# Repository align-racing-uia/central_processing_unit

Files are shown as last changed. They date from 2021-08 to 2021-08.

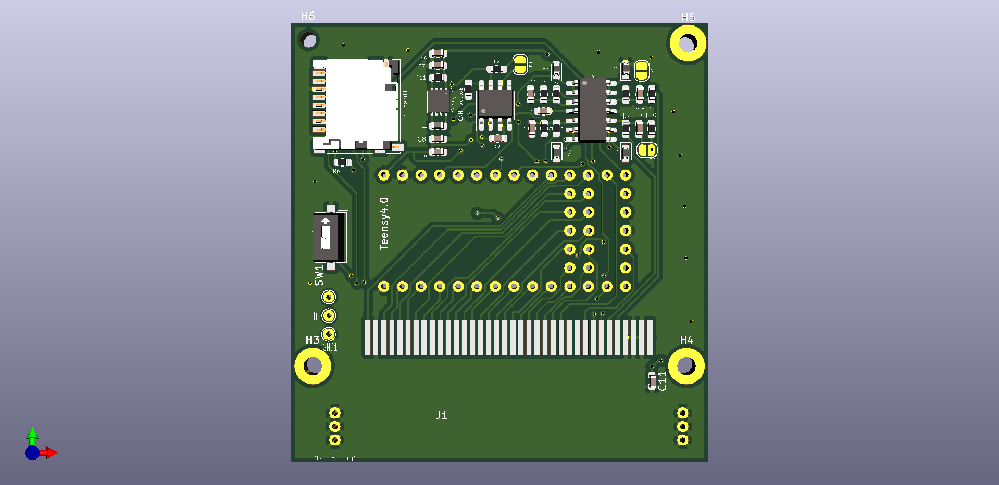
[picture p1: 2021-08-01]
cpu_pcb/breakout/teensy4_header_breakout.png

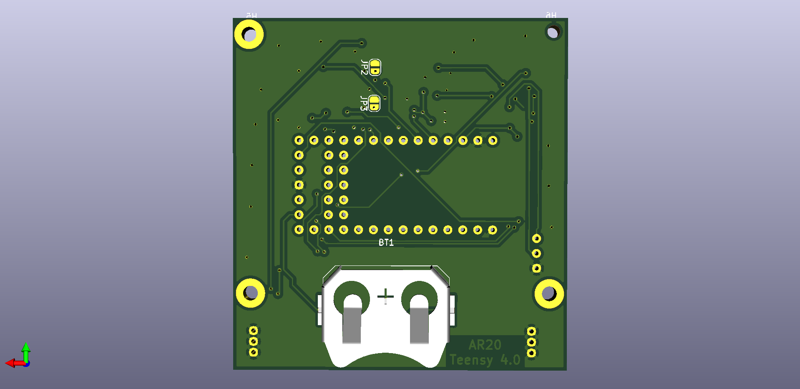
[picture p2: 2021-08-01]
cpu_pcb/breakout/teensy4_header_breakout_back.png

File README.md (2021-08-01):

<h1 align="center"> Central Processing Unit </h1> <br>
<p align="center">
    <a href="http://www.alignracing.no/">
      Align Racing UiA
    </a>
</p>

<!-- START doctoc generate TOC please keep comment here to allow auto update -->
<!-- DON'T EDIT THIS SECTION, INSTEAD RE-RUN doctoc TO UPDATE -->
## Table of contents

- [Introduction](#introduction)
- [Align Racing UiA](#alignracinguia)
- [Rules for file structure](#rulesforfilestructure)
- [License](#license)

<!-- END doctoc generated TOC please keep comment here to allow auto update -->

## Introduction

This is the repository for Align Racing's formula student race car's different systems.

## Align Racing UiA

<a href="http://www.alignracing.no/">Align Racing UiA (AR)</a> is a multidisciplinary student organisation at <a href="https://www.uia.no/">The University of Agder (UiA)</a>, that take part in the world’s largest yearly engineering competition; <a href="https://www.imeche.org/events/formula-student">Formula Student (FS)</a>. The organisation continuously consists of around 60 students, from a wide variety of disciplines. The competition includes developing, building, budgeting and marketing a small scale formula type racing car. AR takes this a bit further by having more focus on developing a strong organisation, open for all disciplines, that gives the members a taste of future work-life.

## Rules

## Contribution

## License
All content included in this Git repository is under the license:

Creative Commons Attribution-NonCommercial-ShareAlike 4.0 International

You are free to:
* <b> Share </b> — copy and redistribute the material in any medium or format
* <b> Adapt </b> — remix, transform, and build upon the material

Under the following terms:
* <b> Attribution </b> — You must give appropriate credit, provide a link to the license, and indicate if changes were made. You may do so in any reasonable manner, but not in any way that suggests the licensor endorses you or your use.
* <b> NonCommercial </b> — You may not use the material for commercial purposes.
* <b> ShareAlike </b> — If you remix, transform, or build upon the material, you must distribute your contributions under the same license as the original.
* <b> No additional restrictions </b> — You may not apply legal terms or technological measures that legally restrict others from doing anything the license permits.

<p align="center">
License
</p>

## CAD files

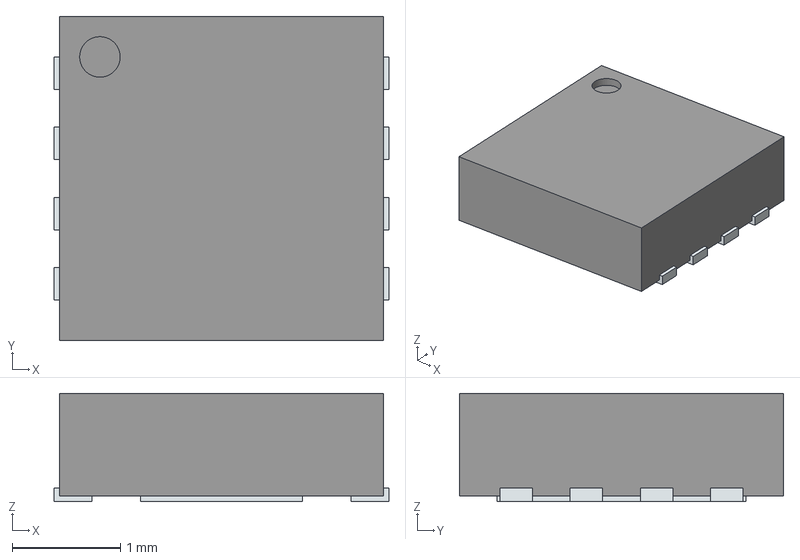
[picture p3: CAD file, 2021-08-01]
cpu_pcb/breakout/NCV890430/NCV890430MW50TXG.stp
3.10 x 3.00 x 1.00 mm
ThermalPin
PinsArrayLR

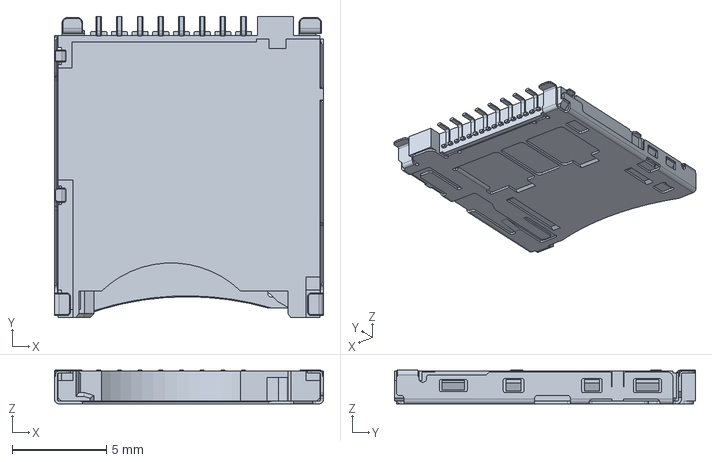
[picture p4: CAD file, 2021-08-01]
cpu_pcb/breakout_2_layers_V2.0/3D_Components/5027740891.stp
14.3 x 16.0 x 1.80 mm

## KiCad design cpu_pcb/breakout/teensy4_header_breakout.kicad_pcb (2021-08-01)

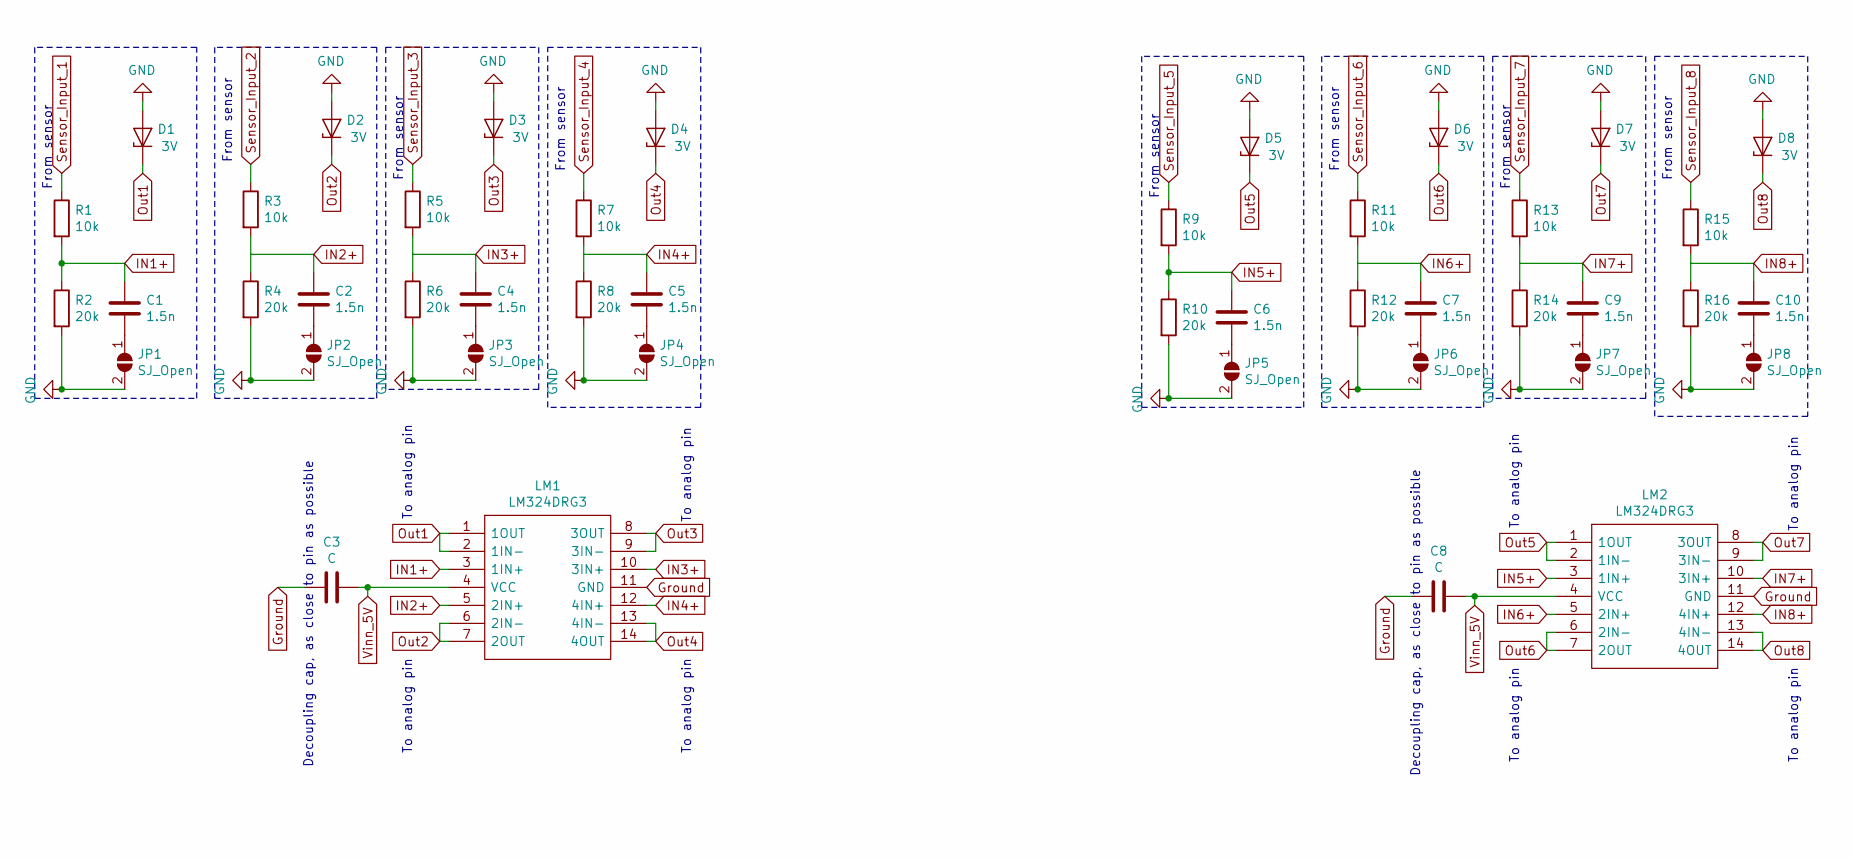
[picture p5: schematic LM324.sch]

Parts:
C1, C2, C4, C5, C6, C7, C9, C10: 1.5n; C_0603_1608Metric
C3, C8: C; C_0603_1608Metric
D1, D2, D3, D4, D5, D6, D7, D8: 3V; D_0603_1608Metric
JP1, JP2, JP3, JP4, JP5, JP6, JP7, JP8: SJ_Open; SolderJumper-2_P1.3mm_Open_RoundedPad1.0x1.5mm
LM1, LM2: LM324DRG3; SOIC-14_3.9x8.7mm_P1.27mm; Manufacturer_Part_Number LM324DRG3; Mouser Part Number 595-LM324DRG3
R1, R3, R5, R7, R9, R11, R13, R15: 10k; R_0603_1608Metric
R2, R4, R6, R8, R10, R12, R14, R16: 20k; R_0603_1608Metric

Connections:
Ground: C3.1, C8.1, D1.2 (A), D2.2 (A), D3.2 (A), D4.2 (A), D5.2 (A), D6.2 (A), D7.2 (A), D8.2 (A), JP1.2 (B), JP2.2 (B), JP3.2 (B), JP4.2 (B), JP5.2 (B), JP6.2 (B), JP7.2 (B), JP8.2 (B), LM1.11 (GND), LM2.11 (GND), R2.2, R4.2, R6.2, R8.2, R10.2, R12.2, R14.2, R16.2; also elsewhere on the board
IN1+: C1.1, LM1.3 (1IN+), R1.2, R2.1
IN2+: C2.1, LM1.5 (2IN+), R3.2, R4.1
IN3+: C4.1, LM1.10 (3IN+), R5.2, R6.1
IN4+: C5.1, LM1.12 (4IN+), R7.2, R8.1
IN5+: C6.1, LM2.3 (1IN+), R9.2, R10.1
IN6+: C7.1, LM2.5 (2IN+), R11.2, R12.1
IN7+: C9.1, LM2.10 (3IN+), R13.2, R14.1
IN8+: C10.1, LM2.12 (4IN+), R15.2, R16.1
unnamed: C1.2, JP1.1 (A)
unnamed: C2.2, JP2.1 (A)
unnamed: C4.2, JP3.1 (A)
unnamed: C5.2, JP4.1 (A)
unnamed: C6.2, JP5.1 (A)
unnamed: C7.2, JP6.1 (A)
unnamed: C9.2, JP7.1 (A)
unnamed: C10.2, JP8.1 (A)
Out1: D1.1 (K), LM1.1 (1OUT), LM1.2 (1IN-); also elsewhere on the board
Out2: D2.1 (K), LM1.6 (2IN-), LM1.7 (2OUT); also elsewhere on the board
Out3: D3.1 (K), LM1.8 (3OUT), LM1.9 (3IN-); also elsewhere on the board
Out4: D4.1 (K), LM1.13 (4IN-), LM1.14 (4OUT); also elsewhere on the board
Out5: D5.1 (K), LM2.1 (1OUT), LM2.2 (1IN-); also elsewhere on the board
Out6: D6.1 (K), LM2.6 (2IN-), LM2.7 (2OUT); also elsewhere on the board
Out7: D7.1 (K), LM2.8 (3OUT), LM2.9 (3IN-); also elsewhere on the board
Out8: D8.1 (K), LM2.13 (4IN-), LM2.14 (4OUT); also elsewhere on the board
Sensor_Input_1: R1.1; also elsewhere on the board
Sensor_Input_2: R3.1; also elsewhere on the board
Sensor_Input_3: R5.1; also elsewhere on the board
Sensor_Input_4: R7.1; also elsewhere on the board
Sensor_Input_5: R9.1; also elsewhere on the board
Sensor_Input_6: R11.1; also elsewhere on the board
Sensor_Input_7: R13.1; also elsewhere on the board
Sensor_Input_8: R15.1; also elsewhere on the board
Vinn_5V: C3.2, C8.2, LM1.4 (VCC), LM2.4 (VCC); also elsewhere on the board

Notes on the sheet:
To analog pin
From sensor
Decoupling cap, as close to pin as possible

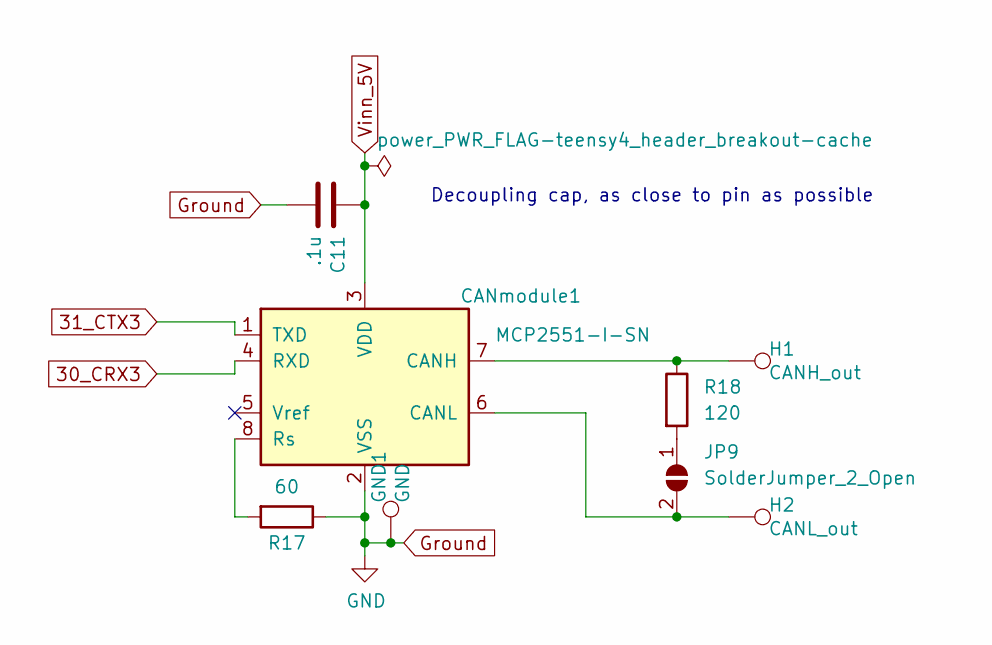
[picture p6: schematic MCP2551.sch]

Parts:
C11: .1u; C_0603_1608Metric
CANmodule1: MCP2551-I-SN; SOIC-8_3.9x4.9mm_P1.27mm
GND1: GND; TestPoint_THTPad_D2.0mm_Drill1.0mm
H1: CANH_out; TestPoint_THTPad_D2.0mm_Drill1.0mm
H2: CANL_out; TestPoint_THTPad_D2.0mm_Drill1.0mm
JP9: SolderJumper_2_Open; SolderJumper-2_P1.3mm_Open_RoundedPad1.0x1.5mm
R17: 60; R_0603_1608Metric_Pad1.05x0.95mm_HandSolder
R18: 120; R_0603_1608Metric_Pad1.05x0.95mm_HandSolder

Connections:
30_CRX3: CANmodule1.4 (RXD); also elsewhere on the board
31_CTX3: CANmodule1.1 (TXD); also elsewhere on the board
Ground: C11.2, CANmodule1.2 (VSS), GND1.1, R17.1; also elsewhere on the board
unnamed: CANmodule1.6 (CANL), H2.1, JP9.2 (B)
unnamed: CANmodule1.7 (CANH), H1.1, R18.1
unnamed: CANmodule1.8 (Rs), R17.2
unnamed: JP9.1 (A), R18.2
Vinn_5V: C11.1, CANmodule1.3 (VDD); also elsewhere on the board

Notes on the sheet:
Decoupling cap, as close to pin as possible

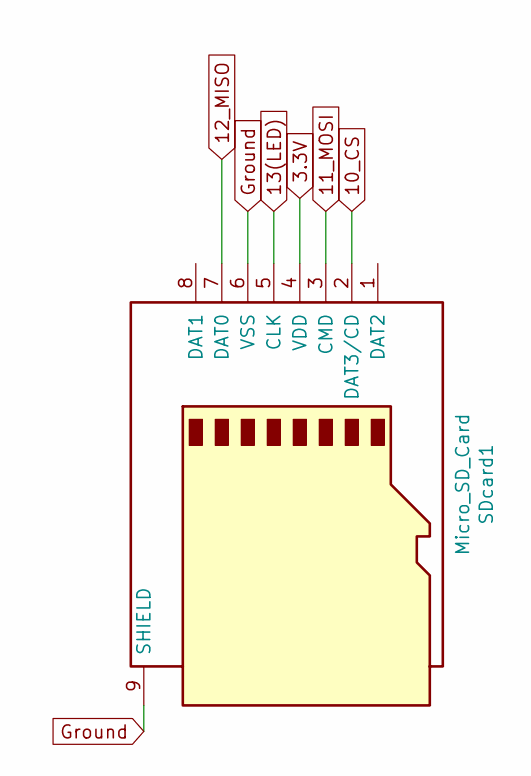
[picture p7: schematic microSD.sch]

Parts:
SDcard1: Micro_SD_Card; microSD_HC_Hirose_DM3D-SF

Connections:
3.3V: SDcard1.4 (VDD); also elsewhere on the board
10_CS: SDcard1.2 (DAT3/CD); also elsewhere on the board
11_MOSI: SDcard1.3 (CMD); also elsewhere on the board
12_MISO: SDcard1.7 (DAT0); also elsewhere on the board
13(LED): SDcard1.5 (CLK); also elsewhere on the board
Ground: SDcard1.6 (VSS), SDcard1.9 (SHIELD); also elsewhere on the board

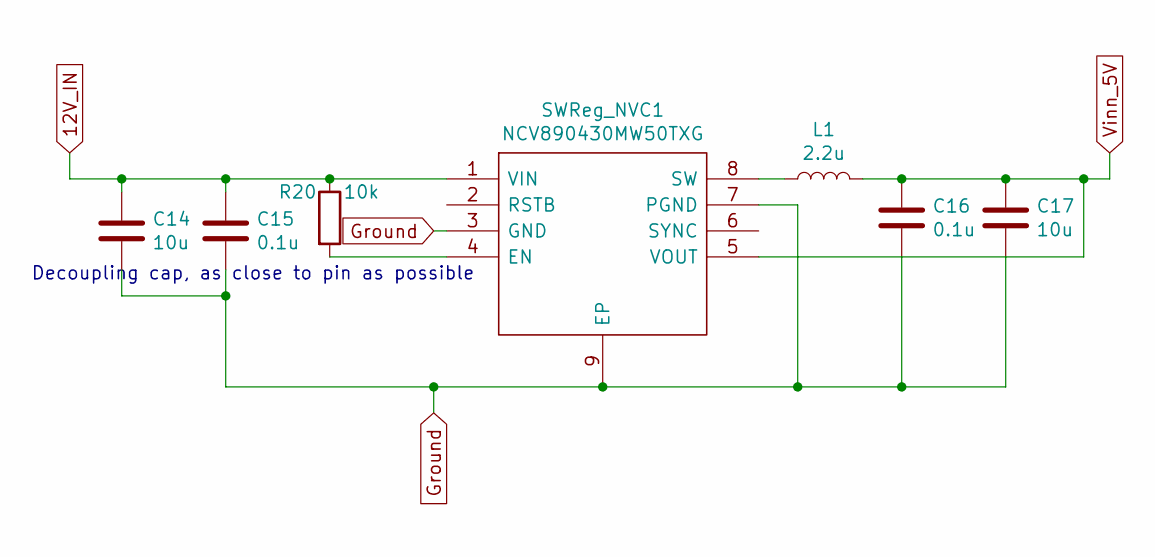
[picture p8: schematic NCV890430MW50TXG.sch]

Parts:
C14, C17: 10u; C_0603_1608Metric
C15, C16: 0.1u; C_0603_1608Metric
L1: 2.2u; L_0603_1608Metric
R20: 10k; R_0603_1608Metric
SWReg_NVC1: NCV890430MW50TXG; DFN-8-1EP_3x3mm_P0.65mm_EP1.7x2.05mm; Manufacturer_Part_Number NCV890430MW50TXG; Mouser Part Number 863-NCV890430MW50TXG

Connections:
12V_IN: C14.1, C15.1, R20.1, SWReg_NVC1.1 (VIN); also elsewhere on the board
Ground: C14.2, C15.2, C16.2, C17.2, SWReg_NVC1.3 (GND), SWReg_NVC1.7 (PGND), SWReg_NVC1.9 (EP); also elsewhere on the board
unnamed: L1.1, SWReg_NVC1.8 (SW)
unnamed: R20.2, SWReg_NVC1.4 (EN)
Vinn_5V: C16.1, C17.1, L1.2, SWReg_NVC1.5 (VOUT); also elsewhere on the board

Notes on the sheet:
Decoupling cap, as close to pin as possible

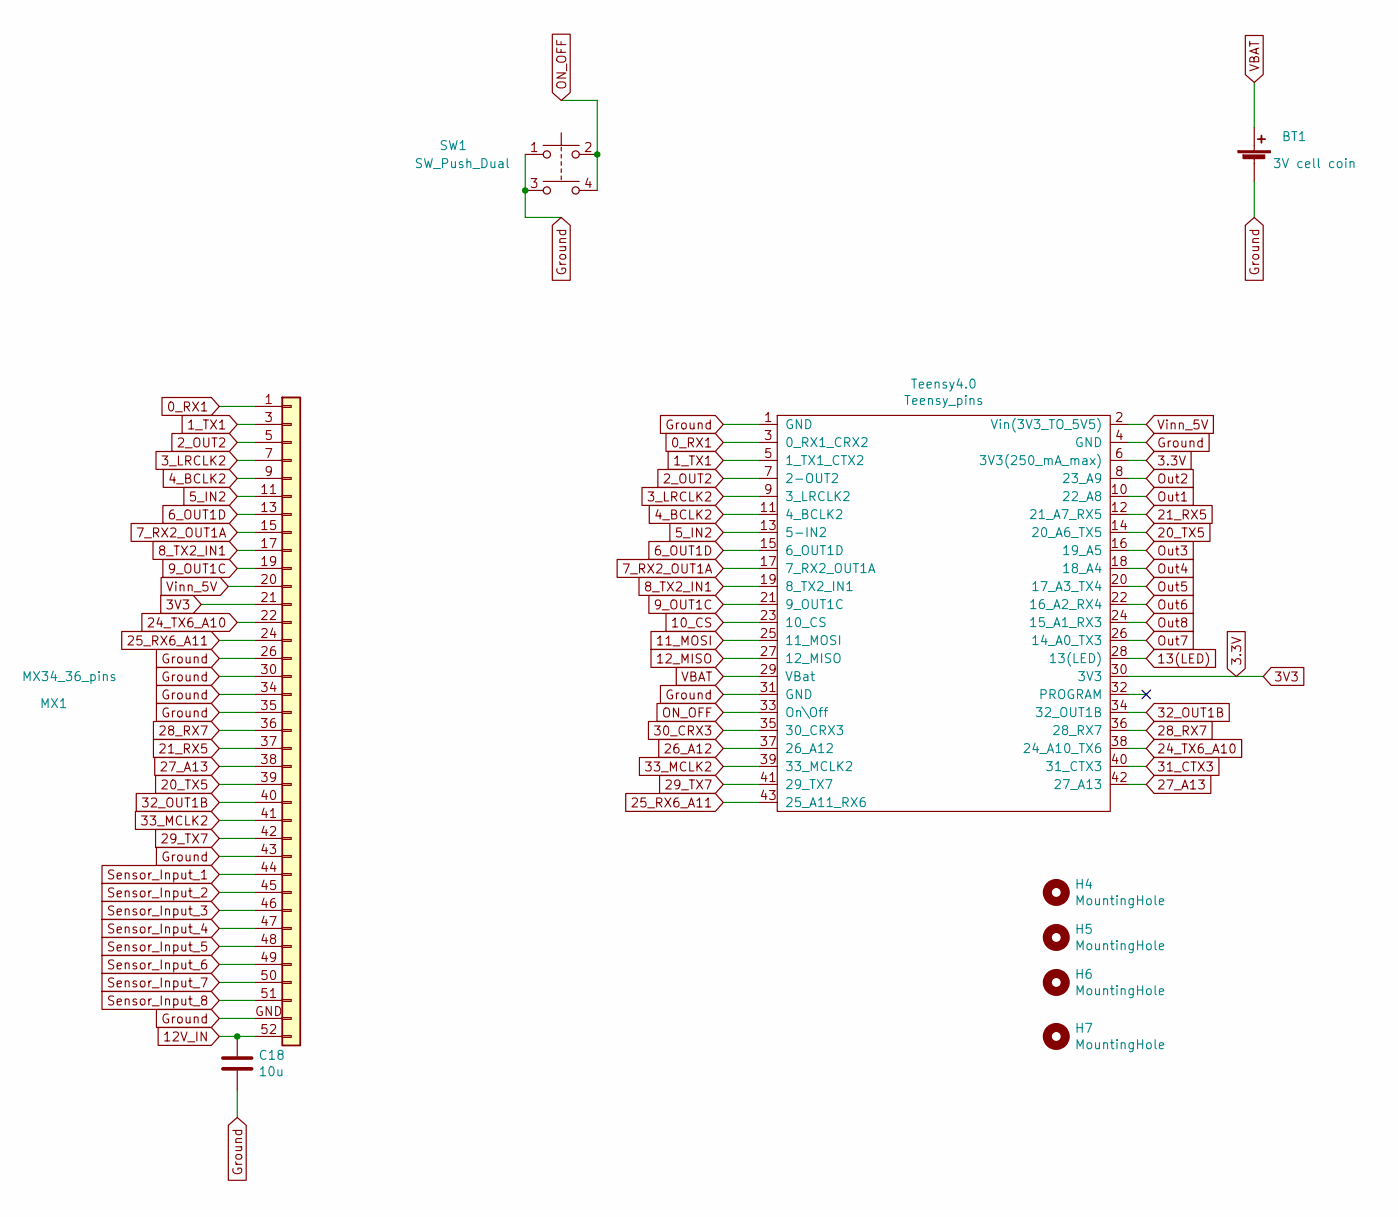
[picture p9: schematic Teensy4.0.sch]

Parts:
BT1: 3V cell coin; BatteryHolder_Keystone_3034_1x20mm
C18: 10u; C_0603_1608Metric
H4, H5, H6, H7: MountingHole; MountingHole_2.5mm_Pad
MX1: MX34_36_pins; Connector_MX34_36pins
SW1: SW_Push_Dual; SW_SPST_B3S-1000
Teensy4.0: Teensy_pins; Teensy_40_footprint

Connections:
0_RX1: MX1.1, Teensy4.0.3 (0_RX1_CRX2)
1_TX1: MX1.3, Teensy4.0.5 (1_TX1_CTX2)
2_OUT2: MX1.5, Teensy4.0.7 (2-OUT2)
3.3V: MX1.21, Teensy4.0.6 (3V3(250_mA_max)), Teensy4.0.30 (3V3); also elsewhere on the board
3_LRCLK2: MX1.7, Teensy4.0.9 (3_LRCLK2)
4_BCLK2: MX1.9, Teensy4.0.11 (4_BCLK2)
5_IN2: MX1.11, Teensy4.0.13 (5-IN2)
6_OUT1D: MX1.13, Teensy4.0.15 (6_OUT1D)
7_RX2_OUT1A: MX1.15, Teensy4.0.17 (7_RX2_OUT1A)
8_TX2_IN1: MX1.17, Teensy4.0.19 (8_TX2_IN1)
9_OUT1C: MX1.19, Teensy4.0.21 (9_OUT1C)
10_CS: Teensy4.0.23 (10_CS); also elsewhere on the board
11_MOSI: Teensy4.0.25 (11_MOSI); also elsewhere on the board
12V_IN: C18.1, MX1.52; also elsewhere on the board
12_MISO: Teensy4.0.27 (12_MISO); also elsewhere on the board
13(LED): Teensy4.0.28 (13(LED)); also elsewhere on the board
20_TX5: MX1.39, Teensy4.0.14 (20_A6_TX5)
21_RX5: MX1.37, Teensy4.0.12 (21_A7_RX5)
24_TX6_A10: MX1.22, Teensy4.0.38 (24_A10_TX6)
25_RX6_A11: MX1.24, Teensy4.0.43 (25_A11_RX6)
27_A13: MX1.38, Teensy4.0.42 (27_A13)
28_RX7: MX1.36, Teensy4.0.36 (28_RX7)
29_TX7: MX1.42, Teensy4.0.41 (29_TX7)
30_CRX3: Teensy4.0.35 (30_CRX3); also elsewhere on the board
31_CTX3: Teensy4.0.40 (31_CTX3); also elsewhere on the board
32_OUT1B: MX1.40, Teensy4.0.34 (32_OUT1B)
33_MCLK2: MX1.41, Teensy4.0.39 (33_MCLK2)
Ground: BT1.2 (-), C18.2, MX1.26, MX1.30, MX1.34, MX1.35, MX1.43, MX1.GND, SW1.1, SW1.3, Teensy4.0.1 (GND), Teensy4.0.4 (GND), Teensy4.0.31 (GND); also elsewhere on the board
ON_OFF: SW1.2, SW1.4, Teensy4.0.33 (On\Off)
Out1: Teensy4.0.10 (22_A8); also elsewhere on the board
Out2: Teensy4.0.8 (23_A9); also elsewhere on the board
Out3: Teensy4.0.16 (19_A5); also elsewhere on the board
Out4: Teensy4.0.18 (18_A4); also elsewhere on the board
Out5: Teensy4.0.20 (17_A3_TX4); also elsewhere on the board
Out6: Teensy4.0.22 (16_A2_RX4); also elsewhere on the board
Out7: Teensy4.0.26 (14_A0_TX3); also elsewhere on the board
Out8: Teensy4.0.24 (15_A1_RX3); also elsewhere on the board
Sensor_Input_1: MX1.44; also elsewhere on the board
Sensor_Input_2: MX1.45; also elsewhere on the board
Sensor_Input_3: MX1.46; also elsewhere on the board
Sensor_Input_4: MX1.47; also elsewhere on the board
Sensor_Input_5: MX1.48; also elsewhere on the board
Sensor_Input_6: MX1.49; also elsewhere on the board
Sensor_Input_7: MX1.50; also elsewhere on the board
Sensor_Input_8: MX1.51; also elsewhere on the board
VBAT: BT1.1 (+), Teensy4.0.29 (VBat)
Vinn_5V: MX1.20, Teensy4.0.2 (Vin(3V3_TO_5V5)); also elsewhere on the board

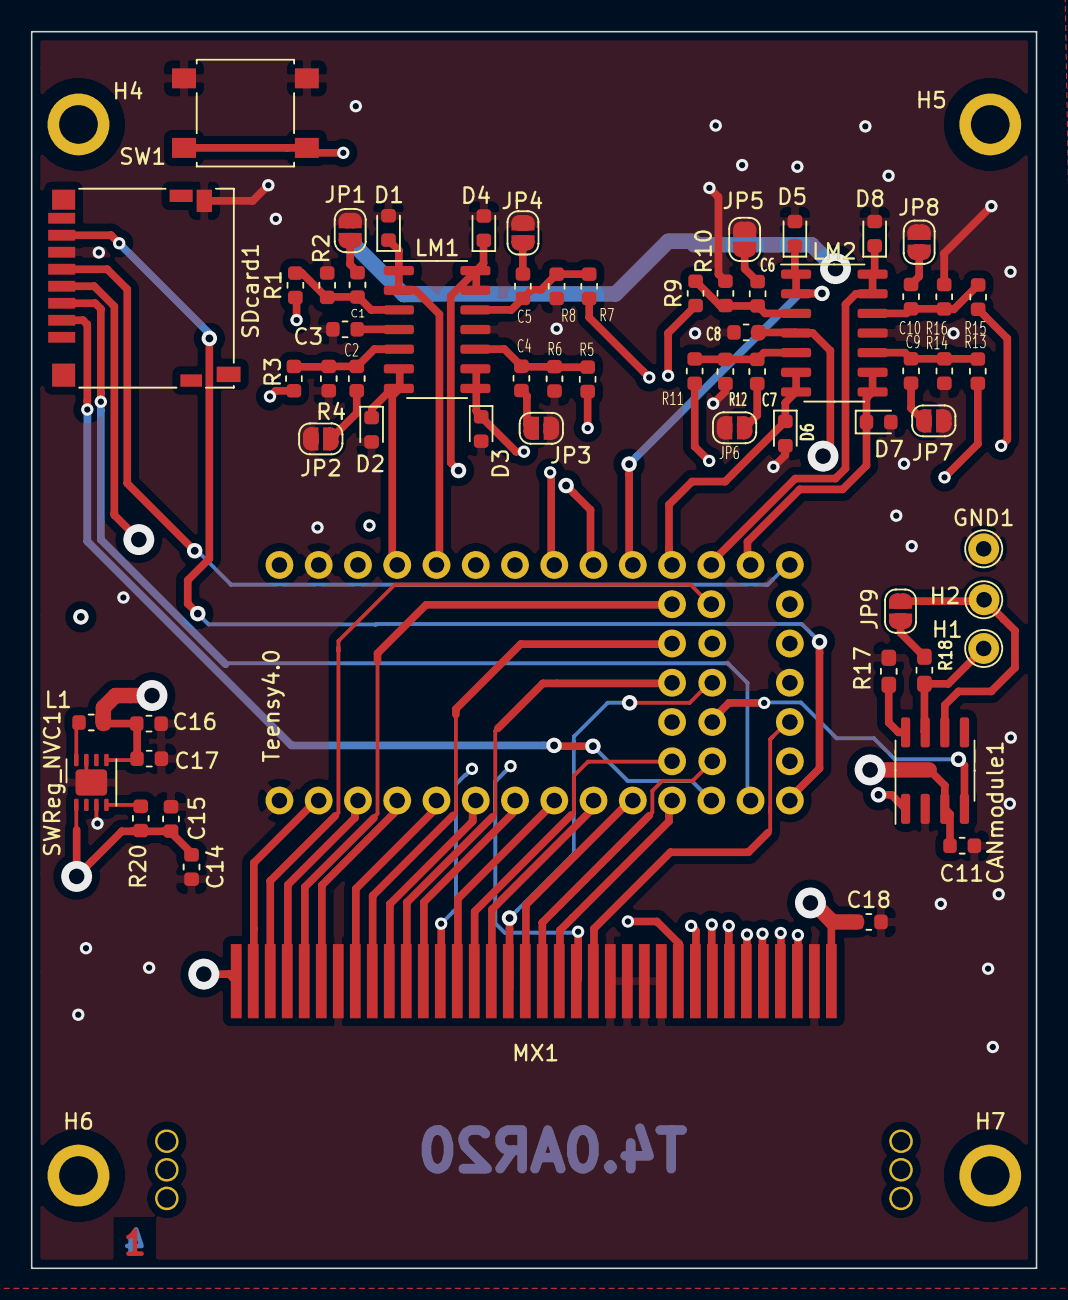
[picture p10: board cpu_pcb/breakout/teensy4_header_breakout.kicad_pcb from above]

Board: 4 copper layers, 65.0 x 80.0 mm, 69 parts (0 on the bottom side), 69 nets.

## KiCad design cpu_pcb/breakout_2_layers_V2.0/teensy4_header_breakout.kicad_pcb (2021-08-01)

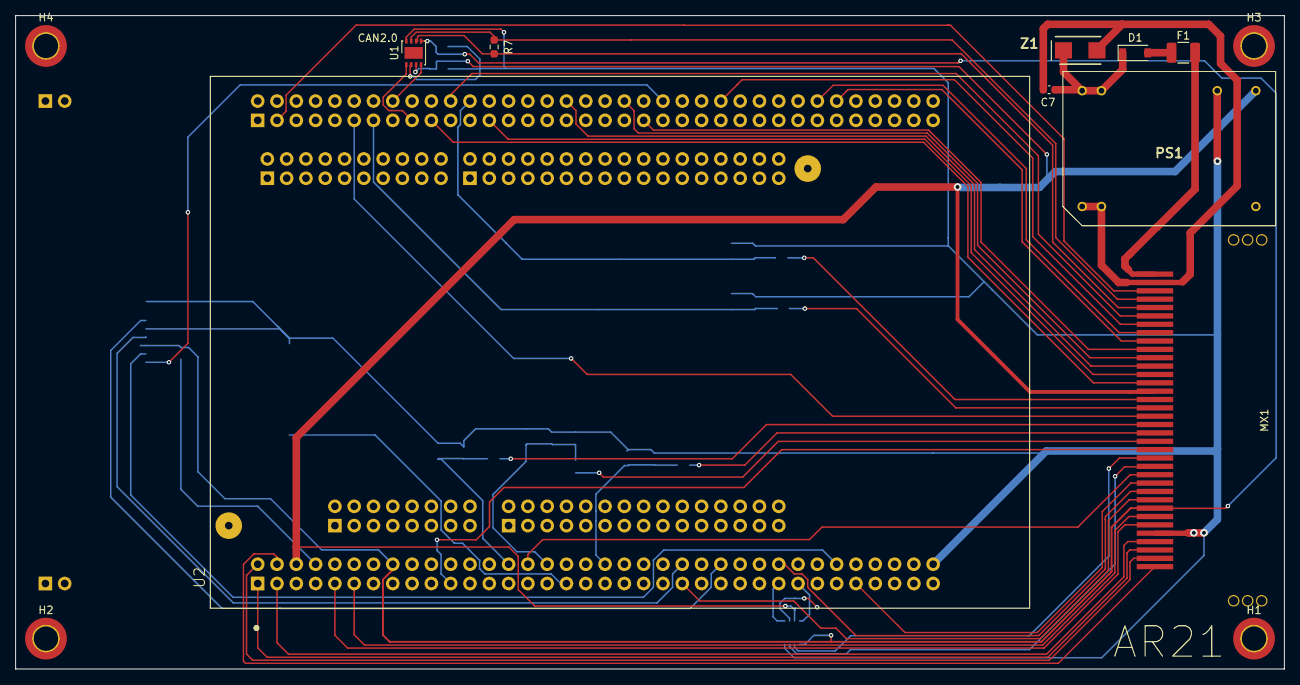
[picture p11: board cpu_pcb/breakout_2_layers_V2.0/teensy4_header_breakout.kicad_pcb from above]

Board: 2 copper layers, 167.0 x 86.0 mm, 38 parts (0 on the bottom side), 52 nets.

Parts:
C1, C2, C3, C4, C5: 15n; C_0603_1608Metric
C6, C7, C8, C9, C10, C11: 10uF; C_0603_1608Metric
D1: D_Schottky_MBR0520LT1G; D_SOD-123-MBR0520LT1G
D2, D3, D4, D5, D6: D_Zener_MM3Z3V6T1G; D_SOD-323-MM3Z3V6T1G
F1: Polyfuse_Small; R_1210_3225Metric_Pad1.30x2.65mm_HandSolder
H1, H2, H3, H4: MountingHole; MountingHole_3.2mm_M3_ISO14580_Pad_TopBottom
MX1: MX34_36_pins; Connector_MX34_36pins
PS1: TEL_5-1211; TEL51211
R1, R2, R3, R4, R5: 10k; R_0603_1608Metric
R6: 20k; R_0603_1608Metric
R7, R8: 120; R_0603_1608Metric_Pad0.98x0.95mm_HandSolder
SDcard1: Micro_SD_Card; Molex_502774-0891
U1, U3: MCP2542WFDxMF; DFN-8-1EP_3x3mm_P0.65mm_EP1.55x2.4mm
U2: NUCLEO-H745ZI-Q; MODULE_NUCLEO-F429ZI
U4: S8211-46R
Z1: 1SMB5930BT3G; DIOM5436X247N

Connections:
4G-RX: MX1.1, U2.CN11_4
4G-TX: MX1.4, U2.CN11_3
12V_GND: C7.1, MX1.35, PS1.2, PS1.3, Z1.2
12V_IN: F1.1, MX1.36
12V_safe: C7.2, D1.1, PS1.22, PS1.23, Z1.1
+3V3: C6.2, C8.2, C10.2, MX1.8, SDcard1.4, U1.5, U2.CN11_16, U3.5
+5V: C9.1, C11.1, MX1.22, PS1.14, U1.3, U2.CN11_6, U3.3
CAN2.0-CANH: MX1.33, R7.1, U1.7
CAN2.0-CANL: MX1.32, R7.2, U1.6
CAN2.0-RX: U1.4, U2.CN12_16
CAN2.0-TX: U1.1, U2.CN12_17
CANFD-CANH: MX1.13, R8.1, U3.7
CANFD-CANL: MX1.14, R8.2, U3.6
CANFD-RX: U2.CN11_57, U3.4
CANFD-TX: U2.CN11_55, U3.1
ClutchPS: MX1.16, R5.1
ClutchPSFiltered: C5.1, D2.1, R5.2, R6.1, U2.CN11_32
GND: C1.2, C2.2, C3.2, C4.2, C5.2, C6.1, C8.1, C9.2, C10.1, C11.2, D2.2, D3.2, D4.2, D5.2, D6.2, MX1.5, PS1.16, R6.2, SDcard1.6, SDcard1.9, U1.2, U1.8, U1.9, U2.CN11_8, U2.CN11_72, U2.CN12_72, U3.2, U3.8, U3.9, U4.3
GPIO-analog-ut1: MX1.30, U2.CN12_50
GPIO-analog-ut2: MX1.29, U2.CN12_60
GPIO-digital1: MX1.31, U2.CN12_22
GPIO-digital2: MX1.28, U2.CN12_62
GearPS-CS: MX1.26, U2.CN12_40
GearPS-MISO: MX1.11, U2.CN11_63
GearPS-MOSI: MX1.9, U2.CN11_45
GearPS-SCK: MX1.19, U2.CN12_11
I2C1-SCL: MX1.34, U2.CN12_3
I2C1-SDA: MX1.15, U2.CN11_21
unnamed: D1.2, F1.2
unnamed: U2.CN11_33, U4.1
SD-CS: SDcard1.2, U2.CN12_44
SD-MISO: SDcard1.7, U2.CN11_50
SD-MOSI: SDcard1.3, U2.CN11_62
SD-SCK: SDcard1.5, U2.CN11_46
Servo-IO: MX1.10, U2.CN11_56
Servo-RX: MX1.6, U2.CN11_9
Servo-TX: MX1.7, U2.CN11_11
StearingAS: MX1.25, U2.CN12_34
SusDips-FL: MX1.20, R2.2
SusDips-FR: MX1.18, R1.2
SusDips-RL: MX1.17, R4.2
SusDips-RR: MX1.21, R3.2
SusDipsFiltered-FL: C2.1, D5.1, R2.1, U2.CN12_13
SusDipsFiltered-FR: C1.1, D3.1, R1.1, U2.CN11_28
SusDipsFiltered-RL: C4.1, D6.1, R4.1, U2.CN11_38
SusDipsFiltered-RR: C3.1, D4.1, R3.1, U2.CN12_24
VN-RX: MX1.2, U2.CN11_2
VN-TX: MX1.3, U2.CN11_1
WSHE-FL: MX1.23, U2.CN12_19
WSHE-FR: MX1.24, U2.CN12_25
WSHE-RL: MX1.12, U2.CN11_30
WSHE-RR: MX1.27, U2.CN12_41

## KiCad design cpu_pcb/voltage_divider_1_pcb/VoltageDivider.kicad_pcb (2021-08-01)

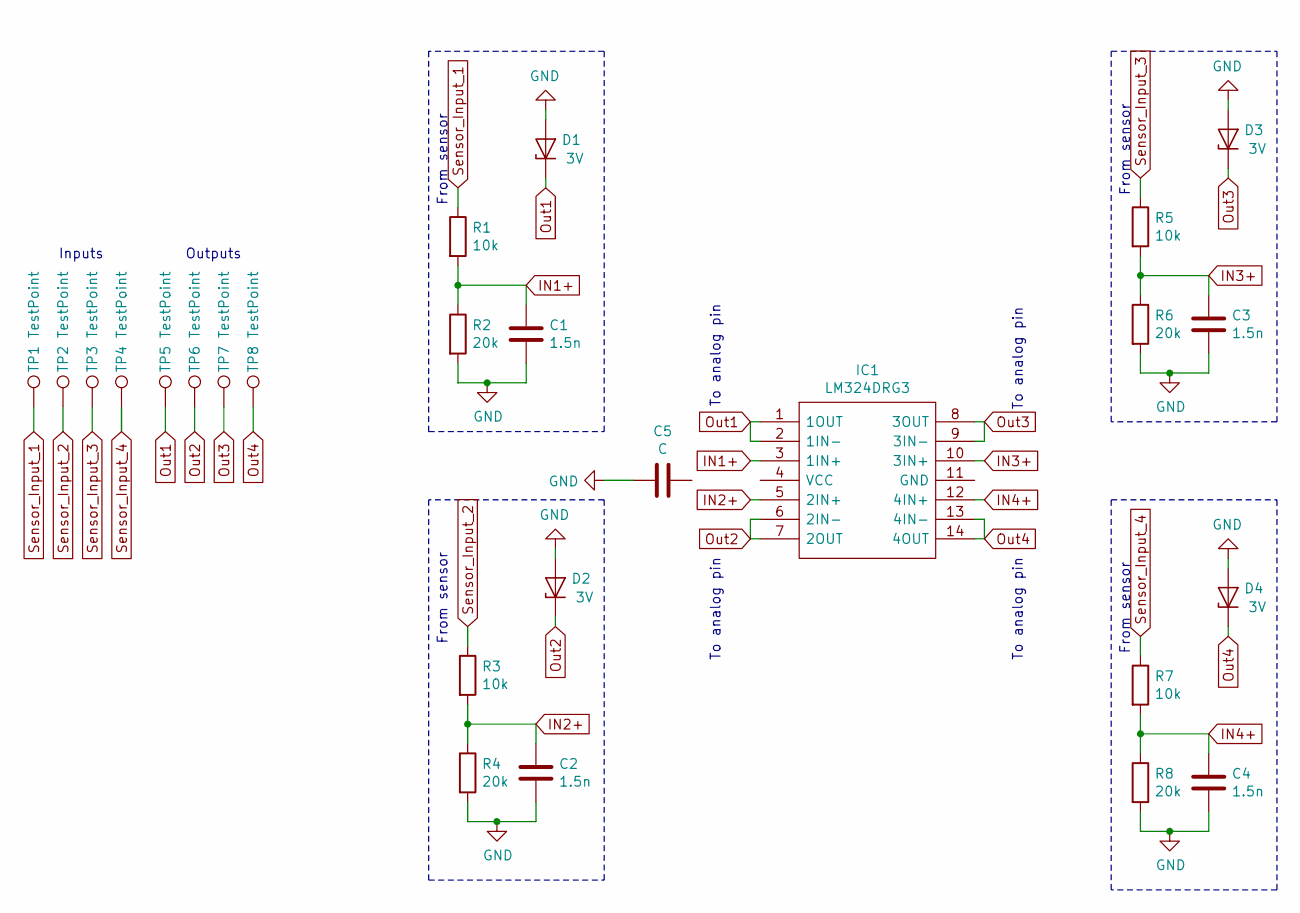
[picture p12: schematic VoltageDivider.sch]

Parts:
C1, C2, C3, C4: 1.5n; C_0603_1608Metric
C5: C; C_0603_1608Metric
D1, D2, D3, D4: 3V; D_0603_1608Metric
IC1: LM324DRG3; SOIC127P600X175-14N; Manufacturer_Part_Number LM324DRG3; Mouser Part Number 595-LM324DRG3
R1, R3, R5, R7: 10k; R_0603_1608Metric
R2, R4, R6, R8: 20k; R_0603_1608Metric
TP1, TP2, TP3, TP4, TP5, TP6, TP7, TP8: TestPoint; TestPoint_THTPad_D1.0mm_Drill0.5mm

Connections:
GND: C1.2, C2.2, C3.2, C4.2, C5.1, D1.2 (A), D2.2 (A), D3.2 (A), D4.2 (A), R2.2, R4.2, R6.2, R8.2
IN1+: C1.1, IC1.3 (1IN+), R1.2, R2.1
IN2+: C2.1, IC1.5 (2IN+), R3.2, R4.1
IN3+: C3.1, IC1.10 (3IN+), R5.2, R6.1
IN4+: C4.1, IC1.12 (4IN+), R7.2, R8.1
Out1: D1.1 (K), IC1.1 (1OUT), IC1.2 (1IN-), TP5.1
Out2: D2.1 (K), IC1.6 (2IN-), IC1.7 (2OUT), TP6.1
Out3: D3.1 (K), IC1.8 (3OUT), IC1.9 (3IN-), TP7.1
Out4: D4.1 (K), IC1.13 (4IN-), IC1.14 (4OUT), TP8.1
Sensor_Input_1: R1.1, TP1.1
Sensor_Input_2: R3.1, TP2.1
Sensor_Input_3: R5.1, TP3.1
Sensor_Input_4: R7.1, TP4.1

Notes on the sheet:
From sensor
To analog pin
Inputs
Outputs

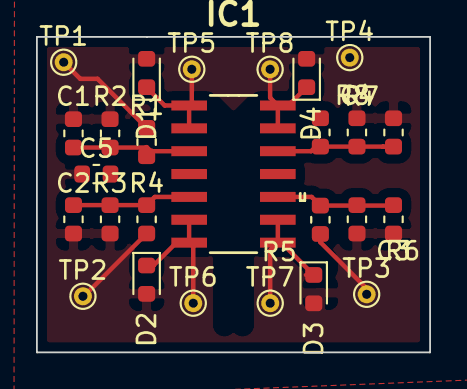
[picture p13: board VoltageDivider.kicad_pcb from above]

Board: 2 copper layers, 21.8 x 17.5 mm, 26 parts (0 on the bottom side), 13 nets.

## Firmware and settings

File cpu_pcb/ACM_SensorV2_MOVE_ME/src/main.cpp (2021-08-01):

#include <Arduino.h>
#include <ACAN2517FD.h>
#include <SPI.h>


//——————————————————————————————————————————————————————————————————————————————
//  Test setup
//——————————————————————————————————————————————————————————————————————————————

const uint8_t btn_pin = 3; // D3
//const uint8_t led_pin = 5; // Intern lys
const uint8_t exled_pin = 17; // A3

uint8_t led_state = LOW;

unsigned long time; // For interrupt timing
unsigned long elapsed_time; // For interrupt timing
volatile int count = 0;

unsigned long sendingTime; // For SDS sending timing
float analogVoltage = 0;
int wheelspeed = 0;


//——————————————————————————————————————————————————————————————————————————————
//  CANBUS setup
//——————————————————————————————————————————————————————————————————————————————

static const byte MCP2517_CS  = 7; // CS input of MCP2517
static const byte MCP2517_INT =  2; // INT output of MCP2517

ACAN2517FD can(MCP2517_CS, SPI, MCP2517_INT);
CANFDMessage FDsuspentionValue, FDwheelspeed;

void sendFDData(CANFDMessage FDmessage) {
  can.tryToSend(FDmessage);
}

void toggle();

//——————————————————————————————————————————————————————————————————————————————
//  Generell setup
//——————————————————————————————————————————————————————————————————————————————

void setup() {
	/* --------------------------- Interrupt setup --------------------------- */
	pinMode(btn_pin, INPUT); // D3
	//pinMode(led_pin, OUTPUT); // Internt lys
	pinMode(exled_pin, OUTPUT); // A3

	attachInterrupt(digitalPinToInterrupt(btn_pin), toggle, RISING);


	time = millis(); 
    sendingTime = millis(); 

	/* --------------------------- CANbus setup --------------------------- */
	SPI.begin();

  	ACAN2517FDSettings settings(ACAN2517FDSettings::OSC_20MHz, 500UL * 1000UL, DataBitRateFactor::x8);
	settings.mRequestedMode = ACAN2517FDSettings::NormalFD;
 	settings.mDriverTransmitFIFOSize = 1;
  	settings.mDriverReceiveFIFOSize = 1;
	
	const uint32_t errorCode = can.begin(settings, [] { can.isr () ; });
	if (errorCode != 0) {

  	}

  	/* -------------------------------------------------------------------------- */
  	/*                               Sending frames                               */
  	/* -------------------------------------------------------------------------- */

  	// Verdien til suspension displacement value
  	FDsuspentionValue.id = 0x420;
  	FDsuspentionValue.len = 1; // Valid lengths are: 0, 1, ..., 8, 12, 16, 20, 24, 32, 48, 64
  	FDsuspentionValue.type = CANFDMessage::CANFD_WITH_BIT_RATE_SWITCH;

	FDwheelspeed.id = 0x424;
  	FDwheelspeed.len = 1; // Valid lengths are: 0, 1, ..., 8, 12, 16, 20, 24, 32, 48, 64
  	FDwheelspeed.type = CANFDMessage::CANFD_WITH_BIT_RATE_SWITCH;

	//Serial.begin(9600);
}

void loop() {
	if(count == 12) {
		elapsed_time = millis() - time;
		time = millis();

		wheelspeed = 123;
		//led_state = !(led_state);
		//digitalWrite(led_pin, led_state);
		count = 0;


	}

	// Når det har gått 10ms, gjør følgende:
	if (millis() - sendingTime > 1000) {
		analogVoltage = analogRead(14); // Leser fra A0 på breakoutboardet til ACMen
		analogVoltage = (int)(analogVoltage * (5 / 1023.0) * 10); // Konverterer til spenning i millivolt

		FDsuspentionValue.data[0] = analogVoltage;
		FDwheelspeed.data[0] = wheelspeed;

		sendFDData(FDsuspentionValue);
		sendFDData(FDwheelspeed);
		//Serial.println(analogVoltage);

	    sendingTime = millis();
	}

}

// Skrur LED av/på ved knappetrykk
void toggle() {
 	// Koblet til ekstern LED
	count++;
	led_state = !(led_state);
	digitalWrite(exled_pin, led_state);
}

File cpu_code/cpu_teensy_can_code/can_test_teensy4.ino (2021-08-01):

#include <FlexCAN_T4.h>

FlexCAN_T4<CAN1, RX_SIZE_256, TX_SIZE_16> FD;

void setup(void) {
  Serial.begin(9600); delay(500);
 // pinMode(6, OUTPUT); digitalWrite(6, LOW);
  

FD.begin();
FD.setBaudRate(500000);
}


void loop() {
  CAN_message_t msg;
  msg.len = 8; msg.id = 0x321;
  msg.buf[0] = 1; msg.buf[1] = 2; msg.buf[2] = 3; msg.buf[3] = 4;
  msg.buf[4] = 5; msg.buf[5] = 6; msg.buf[6] = 7; msg.buf[7] = 8;
  FD.write(msg);
  
  if ( FD.read(msg) ) {
    //Serial.println("MB: "); Serial.print(msg.mb);
    Serial.print("  ID: 0x"); Serial.print(msg.id, HEX );
    //Serial.print("  EXT: "); Serial.print(msg.flags.extended );
    Serial.print("  LEN: "); Serial.print(msg.len);
    Serial.print(" DATA: ");
    for ( uint8_t i = 0; i < 8; i++ ) {
      Serial.print(msg.buf[i]); Serial.print(" ");
    }
    Serial.print("  TS: "); Serial.println(msg.timestamp);
  }
  delay(50);
}

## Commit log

2021-08-01 Cleanup and renaming.
    [5027740891.stp, LM324.sch, MCP2551.sch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]
2021-08-01 Moved folders.
    [5027740891.stp, LM324.sch, MCP2551.sch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]
